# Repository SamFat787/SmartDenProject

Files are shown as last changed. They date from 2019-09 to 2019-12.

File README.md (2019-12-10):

# SmartDenProject

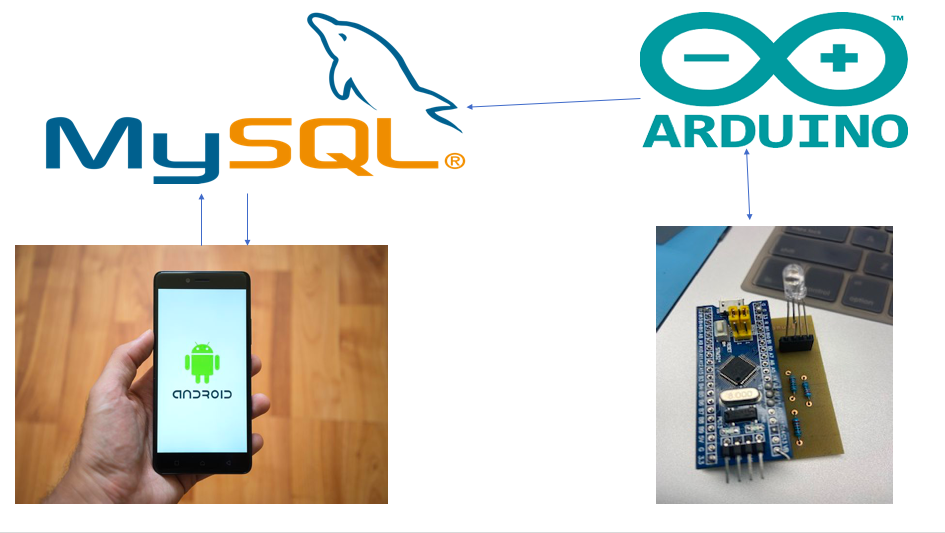
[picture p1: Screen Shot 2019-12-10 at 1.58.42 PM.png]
System diagram


## Samuel Fatuga

https://github.com/SamFat787/SmartDenProject

## Introduction

For our capstone project my partners (Boswell and Bobby) have decided to create a model smarthome. The goal was to make a project for Makerkids, which helps to familiarize young kids with technology. Our intention was to make a project that would use sensors that the kids are familiar with, so they can in turn hack or interact with the project. Our smarthome will be interactive with an Android application that would allow you to interact with the sensors. As far as backend, we plan on storing user settings in our database using MySql. These settings include: temperature readings, record of the time the lights are on/off, and also store the number of sensors a user would have in their smarthome. For my part, I chose an  RGB LED that would allow the user to change a room light to what every they desire. My controller of choice is a STM32 blue pill which is about the size of a Rasberry Pi and with the capabilities of an Arduino Uno. The blue pill has a faster processesor and larger flash than the Arduino and is less expensive.

## Materials Needed
1. BreadBoard
2. YSL-R596CR3G4B5C-C10 https://microcontrollershop.com/product_info.php?products_id=3471&osCsid=t4jclqm2gnqlotp2flii7k57q6
3. STM32F103C8T6 https://www.amazon.ca/STM32-Blue-Pill-Genuine-STM32F103C8T6/dp/B07S2VF1PZ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
4. 3x 220ohm resistors(you can used 100-1k resistors for the LED)
5. ST-Link
6. Arduino IDE https://www.arduino.cc/en/main/software
7. 4 pin header
8. 2x 20 pin headers
9. [case file](https://github.com/SamFat787/SmartDenProject/blob/master/case.stl)
10. [lid file](https://github.com/SamFat787/SmartDenProject/blob/master/ProjectBoxLidRev01Sam.cdr)

Total cost of the project came to around $65CAD. This includes a purchase of the LED and the Blue Pill which comes package with a St-Link. The Breadboard and resistors I already owned since first year as they were part of my Humber tool kit. The Arduino IDE can be downloaded for free.

## Time Commitment

The most time consuming aspect of the project was waiting for the materials to arrive.  The Blue Pill was not shipped from the Amazon warehouse but from a third party seller, and the LED came from the US and was held at customs for some days. These delays set me back a bit.  But assuming you have the parts, the projected can be completed within a couple hours with this break down:

1. half hour to Solder blue pill pins
2. half hour to solder PCB
3. 10-15 mins to program on IDE
4. 30 mins to build and complete your circuit board
5. 2 hours to make and print a 3d case and lid

## Assembly

Here's an image of the breadboard design of the circuit connection. As you may notice the Fritzing image does not include the LED, that is because my printed PCB would did not fit the legs of my LED. In place of the LED I put a four pin header, which would accomodate the LED. From left to right on the header the connection is as follows: Red leg to pin A1, common cathode to ground, Blue leg to A2, and green leg to A3.

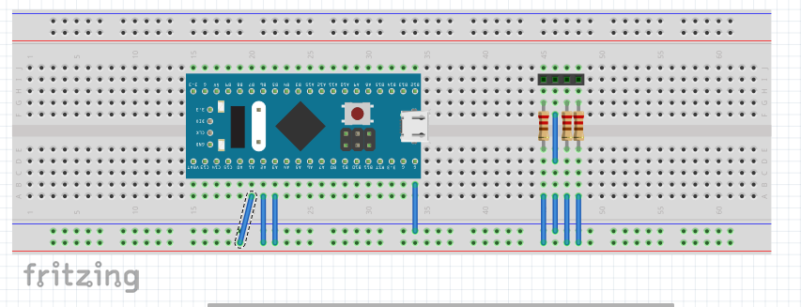
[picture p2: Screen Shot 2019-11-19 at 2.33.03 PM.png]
breadboard


[link to fritzing files](https://github.com/SamFat787/SmartDenProject/blob/master/PCB-CENG%20318.fzz)

## PCB/Soldering
Here is an image of the PCB that shows the connection of the LED legs to the pins of the BluePill. Each leg of the LED require resistors (100ohm to 1kohm) connected in series. A printed soldered PCB is attached below.
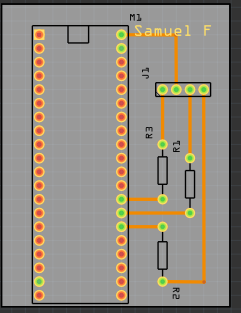
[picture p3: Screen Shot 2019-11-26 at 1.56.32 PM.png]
PCB


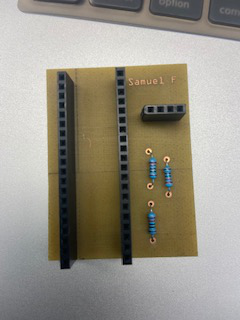
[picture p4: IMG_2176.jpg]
Topview


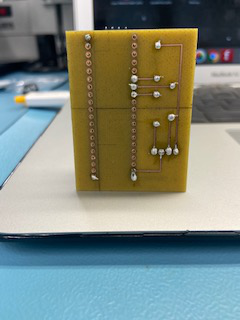
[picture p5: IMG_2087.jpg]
bottom view


## Unit Testing
One of the good things about the Blue Pill is that it can be programmed with Arduino IDE, which uses C++ like syntax. In order to use the controller with the IDE you will first need to add the following to "Additional Boards manager" which can be accessed by File->Preferences: http://dan.drown.org/stm32duino/package_STM32duino_index.json . This allows you to add the board to the list of programmable controllers for the IDE.

Each LED leg is initialized to a pin, then the pin is set as an output. In the main loop the function setColor() cycles through a combination of each color, this allows us to display colors other than Red Green and Blue. If you notice the pins in the code start with PA, but on the board they start with only start with an A. Apperently thats to save space on the board, to program the controller you will need to write the full name of the pin. Below is an image of the Breadboard and the the working PCB.   

[Link to source](https://github.com/SamFat787/SmartDenProject/blob/master/sketch_nov12a.ino)
```
int redPin = PA1;
int greenPin= PA2;
int bluePin= PA3;
void setup() {
  // put your setup code here, to run once:
pinMode(redPin,OUTPUT);
pinMode(greenPin,OUTPUT);
pinMode(bluePin,OUTPUT);
}

void loop() {
 setColor(255, 0, 0); // red
delay(1000);
setColor(0, 255, 0); // green
delay(1000);
setColor(0, 0, 255); // blue
delay(1000);
setColor(255, 255, 0); // yellow
delay(1000);
setColor(80, 0, 80); // purple
delay(1000);
setColor(0, 255, 255); // aqua
delay(1000);
}
void setColor(int red, int green, int blue)
{
#ifdef COMMON_ANODE
red = 255 - red;
green = 255 - green;
blue = 255 - blue;
#endif
analogWrite(redPin, red);
analogWrite(greenPin, green);
analogWrite(bluePin, blue);
}
```

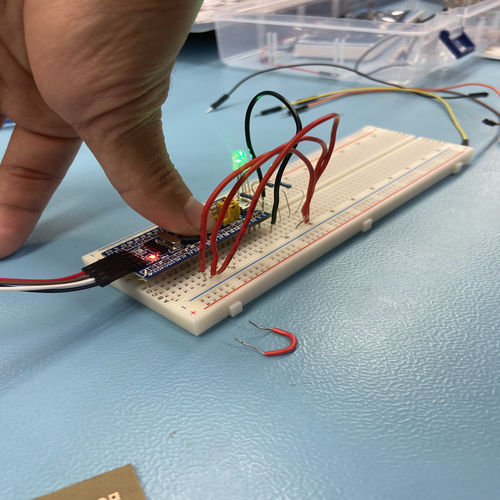
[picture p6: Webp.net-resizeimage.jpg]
Breadboard


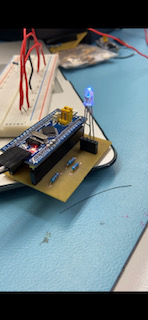
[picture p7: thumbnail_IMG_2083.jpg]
Working PCB


## Production Testing

The case was made at the local Humber prototype lab, normally takes about 2 days to be made.  The acrylic cover can be made in about 10 minutes or so.

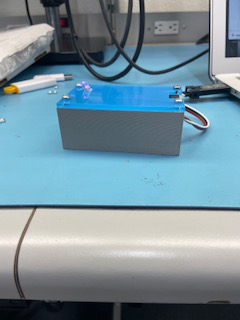
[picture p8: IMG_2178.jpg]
Working case


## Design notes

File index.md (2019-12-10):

<html>
  <body>
    <h2>December 10 working case</h2>
    <p>Took a while but case is finally made and the LED is working properly</p>
    
    <h2>December 3</h2>
    <p>Sent created and sent STL file to the prototype lab for my 3D printed case to be made. They say it should be done in a couple days, hopefully I'll have it by next week.
    <h2>Presentation November 26 2019</h2>
    <p><a href = "https://github.com/SamFat787/SmartDenProject/blob/master/CENG317presentation.pptx">Presentation </a>
      <br/>
      <br/>
    <h2>November 19th</h2>
    <p>After a few weeks of mishaps with previous PCBs (set to digital pins, short in the circuit), I finally got to power up a PCB that runs the code as intended. I havent any purchases since the acquisition of my devices, my budget total is still $68.<p>
    
    <br/>
    <br/>
    Image of the soldered PCB, this delayed the proposed schedule of my project a bit as the first coupld PCB i had made either had a short or were powering the wrong pins.  Here I ran into an issue with one of the ground pins, so I soldered both of them to give my device a ground.
    
    <h2>November 14th</h2>
    <p> Used the Arduino IDE to program the blue pill.  The 3 pins are initialized outside of the main.The mainloop sets the pins outputs, and the main loop will run the function setcolor() which will cycle through the 3 main colors and a combination of other colors. The difficulty in this programming was realizing that i needed to use analog pins and analogWrite() as opposed to to digital pins and a digital function. The image below captures the LED as it is emitting a pink reddish color.
   <p/><br/><p>
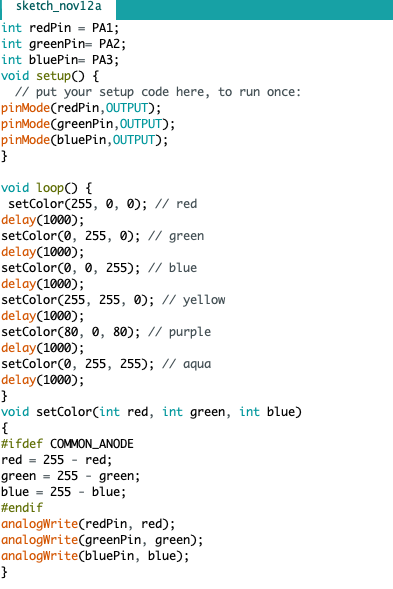
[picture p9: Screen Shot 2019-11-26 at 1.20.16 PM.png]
     <p><br/>
    <br/>
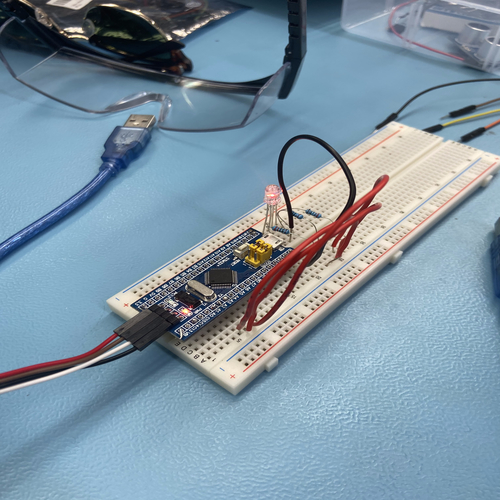
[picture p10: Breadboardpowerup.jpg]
   <br/>
    <p><video width="320" height="240" src="https://github.com/SamFat787/SmartDenProject/blob/master/IMG_2016.MOV">Video</video>
    <h2>Week 8 October 29th</h2>
    <p>All parts arrived over the reading week. RGB LED included a customs duty of $25 that I did not originally budget for a few weeks ago. Made a PCB of the LED/Blue Pill connection
    Connection:<br/> Green in series with a 220ohm resister to A3<br/>
                Blue to in series with a 220ohm resister to A2<br/>
                Common Cathode to Ground<br/>
                red to in series with a 220ohm resister to A1<br/>
    </p><p>
     </p><br/>
    <br/>
    <br/>
    <p>Here is an image of the breadboard, unfortunately the LED may not fit into the connections of a printed PCB so i have placed a 4-pin header in its place.</p>
    <br/>
    
 <br/>
 <h2>Reading Week</h2>
 <p>Both the blue pill and the RGB LED have arrived. The RGB LED required an extra $25 duty charge that I did not budget for. This purchase take my budget from the original $50 to a total of $68. Attached is an image of the LED in my palm.</p>
 <br/>
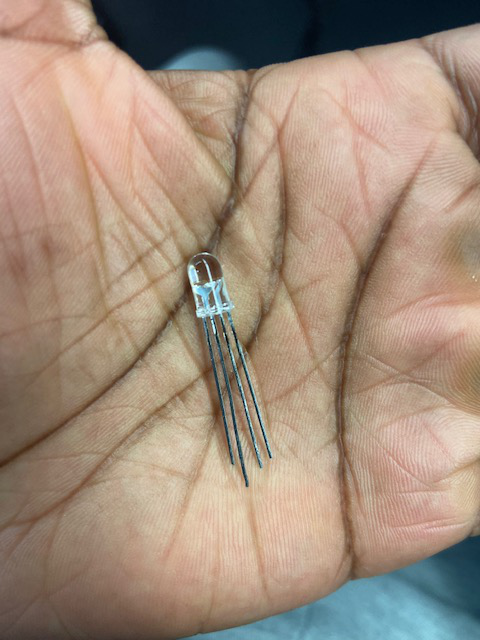
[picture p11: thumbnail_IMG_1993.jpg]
 

   <h2>Week 7 October 15th</h2>
    <p>Both the LED and the STM32 have not arrived yet, the LED i'm assuming is being held at customs and I'm not sure what is holding up the blue pill. I'm hoping both devices arrive during the reading week so i can begin to build my circuit board for the assignment.  The delay in my materials is also delaying the PCB design of my board.  If the materials arrive duringthe break I should get started on the design right away.</p>
    <h2> Week 6 October 8th</h2>
    <p>Ordered the STM32F103C8t6 from amazon for $19.85 with free shipping the device is not being shipped from Amazon's warehouse but rather from Universal Solder. The shipping fee was about $3.50 cad, which currently brings the total spent on the project so far to about $43. I'm currently about $7 under the allocated budget.  The LED has not arrive yet the tracking currently says it's in transition. I'm assuming it's being held up at customs.
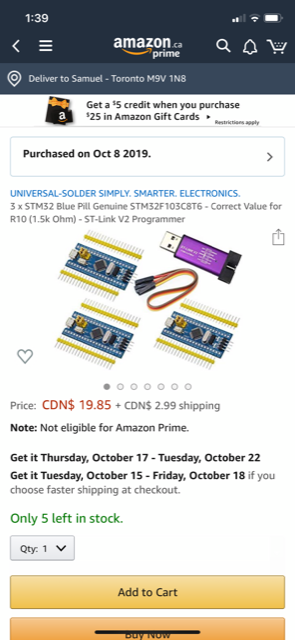
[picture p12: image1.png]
    
    </p>
    <h2>Week 5 October 1st</h2>
    <p>Purchased the LED from Microcontrollershop.com. Store is based in US and part should arrive in the next 5 business days. The shipping cost for the LED is about $12.00 USD bringing the total cost of the the device at $13.98USD or $20CAD.  The device is being shipped first class, so it should arrive some time next week I will update the blog when it arrives.
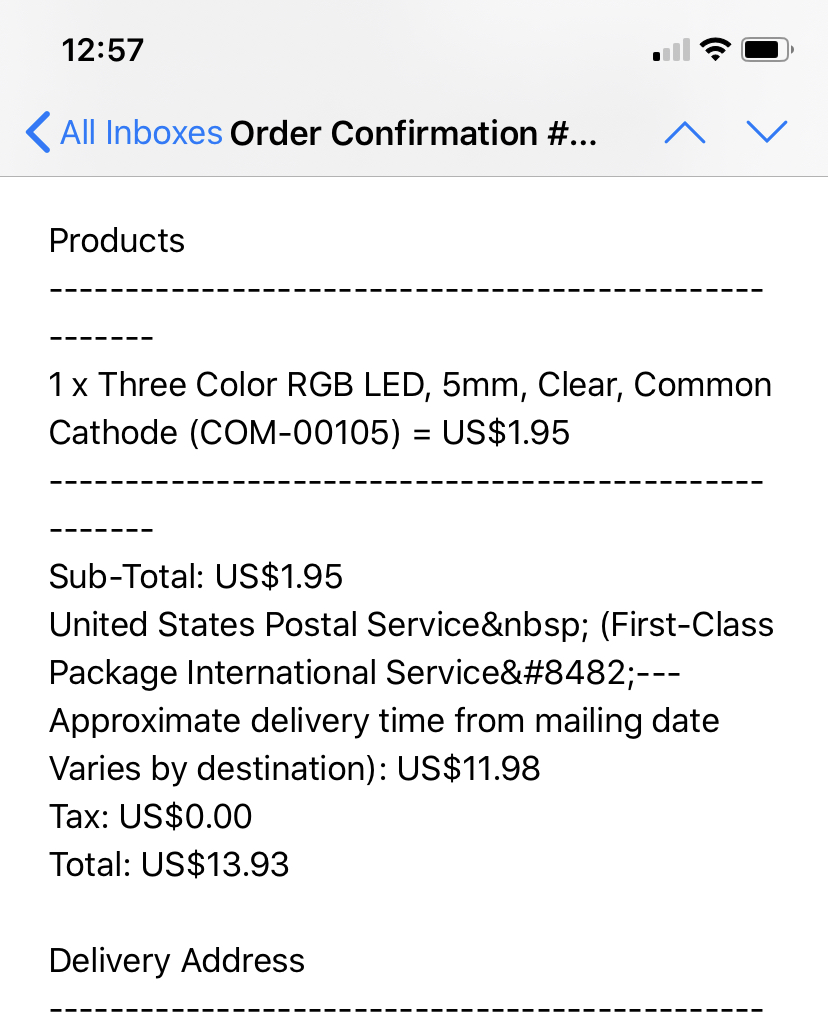
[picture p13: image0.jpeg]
    
    </p>
    <h2>Week 3 September 23</h2>
    <p>Prepared budget for our project after selecting the sensors and effectors each group member will acquire. I will be using the YSL-R596CR3G4B5C-C10 which is an RGB LED. To program the device I will be using an  STM32F103C8T6 microcomputer.  I found the LED at an online retailer for $2.50USD, and the microcontroller is available on Amazon for $19.85. The budget for the sensor and device is planned at $50, to make up for the currency conversion and shipping cost of the LED. The Microcontroller will be shipped for free because I have Amazon prime.</p>
 Testing
    <h2>Week 2 September 17</h2>
    <p>Spoke with team members Boswell and Bobby, and decided on how we will split up the duties. Also prepared a Gantt chart of the production process in order to avoid a watershed process.</p>
   
  <h2>Week1 September 10</h2>
    <p>Selected project thats sponspred by Makerkids.  Our goal is to make a mini smarthome using sensors that the kids of the Makerkids program are familiar with. Uploaded is an image of my proposed schedule for the project</p>
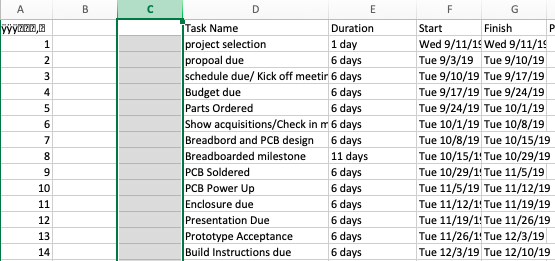
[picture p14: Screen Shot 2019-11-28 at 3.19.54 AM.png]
    <p><p/>

  </body>
  </html>

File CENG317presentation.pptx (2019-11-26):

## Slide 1

Model SmartHome device

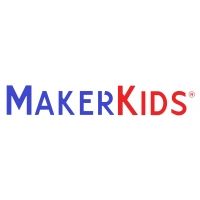
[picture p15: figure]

Samuel Fatuga
CENG 319
Sensor: RGB LED YSL-R596CR3G4B5C-C10

## Proposal

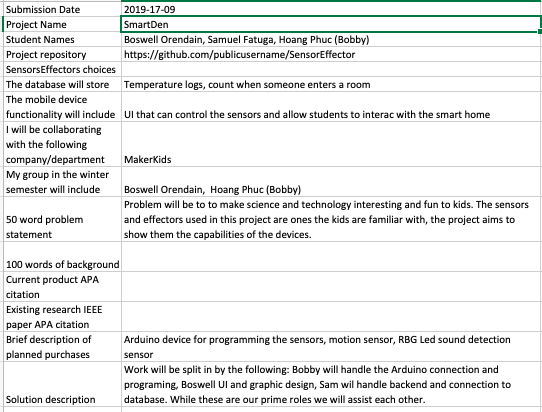
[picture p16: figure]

## Budget

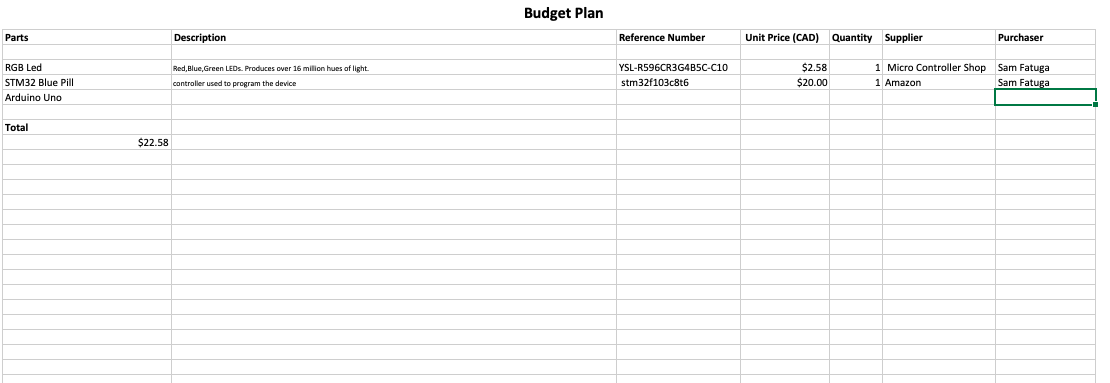
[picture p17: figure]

## SENSOR

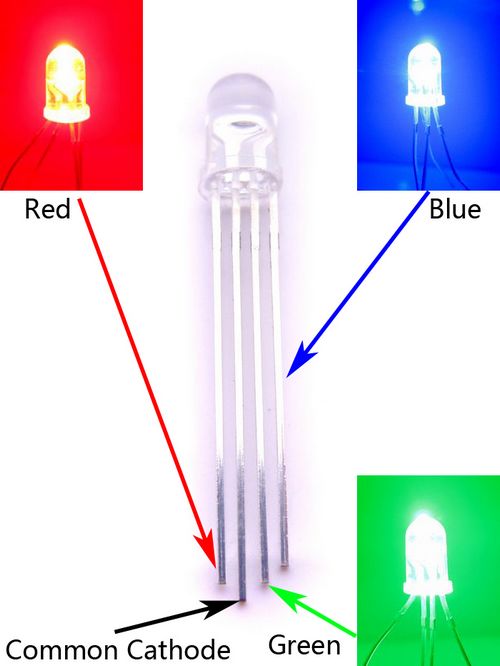
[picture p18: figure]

Can be used as status indicator for each color, or PWM to produce variations of different colors

## Development board

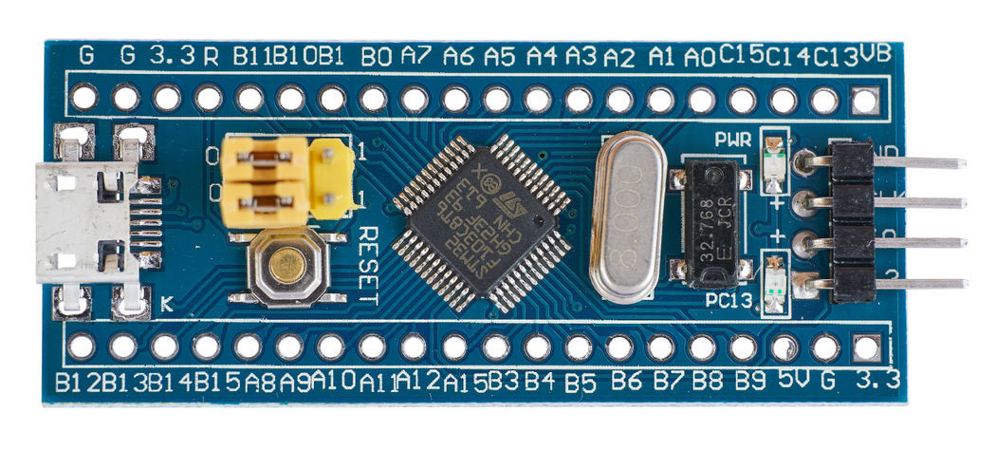
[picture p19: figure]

Less expensive than an Arduino UNO, can be used with with Arduino IDE.
20k RAM and option of 64k or 128k Flash

## Source Code


## Courses that came in handy

- CENG 215 –Digital and Interface Systems
- CENG 252- Embedded Systems
- CENG 209- Micro Assembly Language
- TECH 101-Electric Circuits and Devices

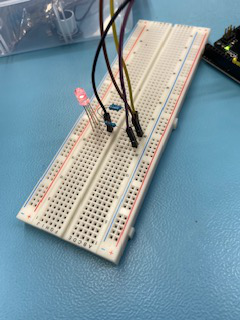
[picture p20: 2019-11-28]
thumbnail_IMG_1944.jpg

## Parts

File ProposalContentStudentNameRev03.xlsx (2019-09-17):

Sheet: DataEntry
Submission Date | 2019-17-09
Project Name | SmartDen
Student Names | Boswell Orendain, Samuel Fatuga, Hoang Phuc (Bobby)
Project repository | https://github.com/publicusername/SensorEffector
SensorsEffectors choices
The database will store | Temperature logs, count when someone enters a room
The mobile device functionality will include | UI that can control the sensors and allow students to interac with the smart home
I will be collaborating with the following company/department | MakerKids
My group in the winter semester will include | Boswell Orendain, Hoang Phuc (Bobby)
50 word problem statement | Problem will be to to make science and technology interesting and fun to kids. The sensors and effectors used in this project are ones the kids are familiar with, the project aims to show them the capabilities of the devices.
100 words of background
Current product APA citation
Existing research IEEE paper APA citation
Brief description of planned purchases | Arduino device for programming the sensors, motion sensor, RBG Led sound detection sensor
Solution description | Work will be split in by the following: Bobby will handle the Arduino connection and programing, Boswell UI and graphic design, Sam wil handle backend and connection to database. While these are our prime roles we will assist each other.

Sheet: DataBase
Submission Date | Project Name | Student Names | Project repository | SensorsEffectors choices | The database will store | The mobile device functionality will include | I will be collaborating with the following company/department | My group in the winter semester will include | 50 word problem statement | 100 words of background | Current product APA citation | Existing research IEEE paper APA citation | Brief description of planned purchases | Solution description
2019-17-09 | SmartDen | Boswell Orendain, Samuel Fatuga, Hoang Phuc (Bobby) | https://github.com/publicusername/SensorEffector | 0 | Temperature logs, count when someone enters a room | UI that can control the sensors and allow students to interac with the smart home | MakerKids | Boswell Orendain, Hoang Phuc (Bobby) | Problem will be to to make science and technology interesting and fun to kids. The sensors and effectors used in this project are ones the kids are familiar with, the project aims to show them the capabilities of the devices. | 0 | 0 | 0 | Arduino device for programming the sensors, motion sensor, RBG Led sound detection sensor | Work will be split in by the following: Bobby will handle the Arduino connection and programing, Boswell UI and graphic design, Sam wil handle backend and connection to database. While these are our prime roles we will assist each other.

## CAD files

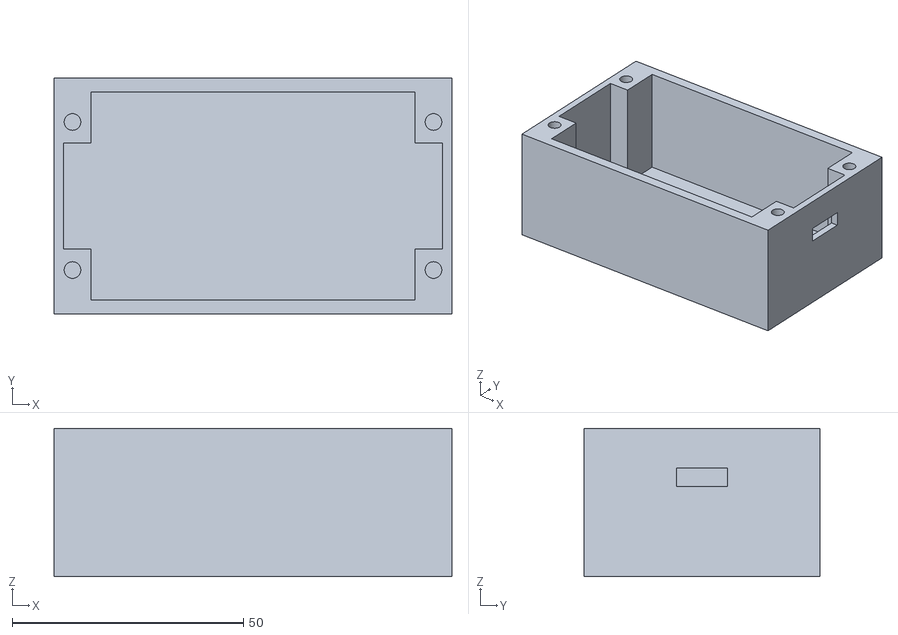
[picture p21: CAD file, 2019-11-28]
case.stl
86.0 x 51.0 x 32.0

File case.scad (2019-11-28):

$fn=64;
difference(){

    {
        xdim2 = 86;
        //need 70 interior
        //ie xdim1-12=70
        //xdim1 = 82
        //an increase of 22
        ydim2 = 51;
        zdim2 = 32;
        translate([-xdim2/2, -ydim2/2, -zdim2])
        {
            cube([xdim2,ydim2,zdim2]);
        }
    }
    xdim1 = 82;
    ydim1 = 23;
    zdim1 = 30;
    //-6.5 was 0 comment of -zdim])
    //positive/negative x end cutout
    translate([-xdim1/2, -ydim1/2, -29.5])
    {
        cube([xdim1,ydim1,zdim1]);
    }
    //programmer cutout
    translate([-xdim1/2+2, -(ydim1-12)/2, -12.5])
    {
        cube([xdim1+2,ydim1-12,4]);
    }
    //positive/negative y side cutout
    translate([-(xdim1-12)/2, -(ydim1+22)/2, -29.5])
    {
        cube([xdim1-12,ydim1+22,zdim1]);
    }
    radius = 1.8;
    translate([-56/2-11,32/2,-10])
    {
        cylinder (18,radius,radius);
    }

    translate([-56/2-11,-32/2,-10])
    {
        cylinder (18,radius,radius);
    }

    translate([56/2+11,32/2,-10])
    {
        cylinder (18,radius,radius);
    }

    translate([56/2+11,-32/2,-10])
    {
        cylinder (18,radius,radius);
    }
    
}

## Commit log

2019-11-26 Create Screen Shot 2019-11-26 at 1.56.32 PM.png
    latest PCB
2019-11-26 PCB Power up
2019-11-27 --bread board/updated PCB
    [SmartDen_Budget.xlsx]
2019-11-28 --solder PCB
2019-11-28 --case dimensions
    [case.scad, case.stl]
2019-12-09 --bluepill pinout
    [SmartDen_Budget.xlsx]
2019-12-10 top view of soldered PCB
2019-12-10 working case
